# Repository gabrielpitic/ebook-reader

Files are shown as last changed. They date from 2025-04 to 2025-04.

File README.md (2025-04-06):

# OpenBook - Gabriel Pitic

## Diagrama bloc

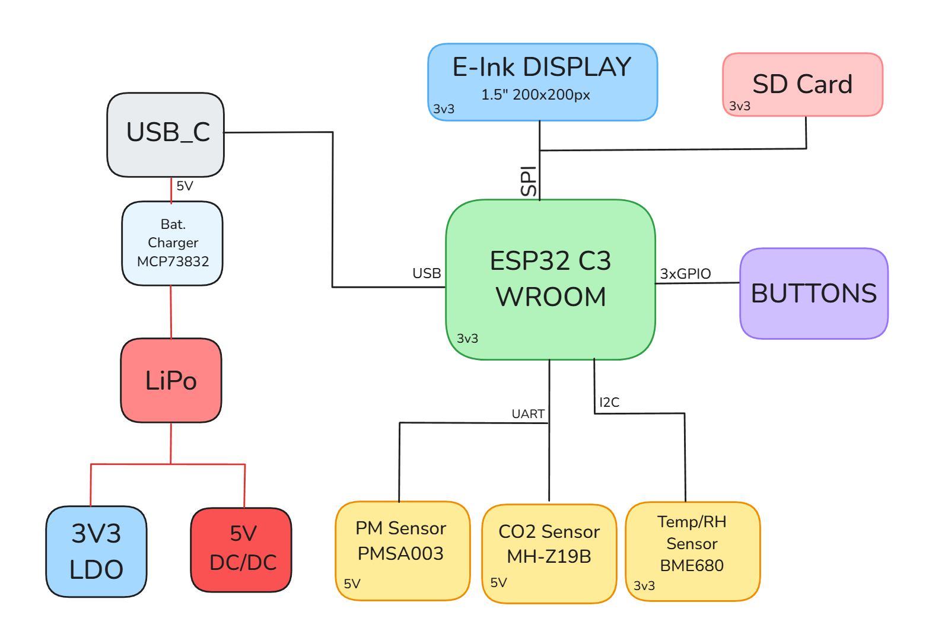
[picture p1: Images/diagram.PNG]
Diagrama bloc


## Bill Of Materials (BOM)
| Componenta | Link | Datasheet |
|---|---|---|
| BD5229G-TR | [Mouser](https://ro.mouser.com/ProductDetail/ROHM-Semiconductor/BD5229G-TR?qs=4kLU8WoGk0vvnhrrYwdszw%3D%3D) | [Datasheet](https://fscdn.rohm.com/en/products/databook/datasheet/ic/power/voltage_detector/bd52xxg-e.pdf)|
| BME688 | [Mouser](https://ro.mouser.com/ProductDetail/Bosch-Sensortec/BME688?qs=IS%252B4QmGtzzqQoVDscqwx3A%3D%3D) | [Datasheet](https://ro.mouser.com/datasheet/2/783/bst_bme688_fl000-2307034.pdf)|
| Bobina | [Mouser](https://ro.mouser.com/ProductDetail/Wurth-Elektronik/744043680?qs=PGXP4M47uW6VkZq%252BkzjrHA%3D%3D) | [Datasheet](https://www.we-online.com/components/products/datasheet/744043680.pdf)|
| Button | [Mouser](https://ro.mouser.com/ProductDetail/CK/KMR221GULCLFS?qs=u2NJ%252B70r0goBXaNk7IrU0Q%3D%3D) |[Datasheet](https://www.ckswitches.com/media/1479/kmr2.pdf)|
| Capacitor 0.1uF / 50V | [Farnell](https://ro.farnell.com/multicomp-pro/mcmlr50v104kx7r/ceramic-capacitor-0-1uf-50v-x7r/dp/1600875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) | [Datasheet](https://www.farnell.com/datasheets/2873577.pdf?_gl=1*x28a2*_gcl_au*MTYwODAzNzc2OC4xNzQzNDM1MjM4)|
| Capacitor 1uF | [Mouser](https://ro.mouser.com/ProductDetail/KEMET/C0402C105K9PACTU?qs=UdQET6xYxVCMExqTDkuPeQ%3D%3D) | [Datasheet](https://ro.mouser.com/datasheet/2/447/KEM_C1006_X5R_SMD-3316465.pdf)|
| Capacitor 1uF / 50V | [Mouser](https://ro.mouser.com/ProductDetail/TDK/C1608X7R1H105K080AB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) | [Datasheet](https://product.tdk.com/system/files/dam/doc/product/capacitor/ceramic/mlcc/catalog/mlcc_commercial_general_en.pdf)|
| Capacitor 4.7uF | [Mouser](https://ro.mouser.com/ProductDetail/KEMET/C0402C475M9PAC7411?qs=cpo3%2FpBou2jRzZxyxJnMGg%3D%3D) | [Datasheet](https://ro.mouser.com/datasheet/2/447/KEM_C1006_X5R_SMD-3316465.pdf)|
| Capacitor 4.7uF / 25V | [Mouser](https://ro.mouser.com/ProductDetail/KYOCERA-AVX/12063C475KAZ2A?qs=%252BdQmOuGyFcG3LdbVp5waMw%3D%3D) | [Datasheet](https://ro.mouser.com/datasheet/2/40/X7RDielectric-2943470.pdf)|
| Capacitor 10uF | [Mouser](https://ro.mouser.com/ProductDetail/KEMET/C0402C106M9PACTU?qs=x4XeXhDQKnp%252Bz0lMlwMC3A%3D%3D) | [Datasheet](https://ro.mouser.com/datasheet/2/447/KEM_C1006_X5R_SMD-3316465.pdf)|
| Capacitor 100nF | [Mouser](https://ro.mouser.com/ProductDetail/KEMET/C0402C104K4RAL?qs=pIZUS6sqCWCaMuP2QVR%2Fog%3D%3D) | [Datasheet](https://ro.mouser.com/datasheet/2/447/KEM_C1018_X7R_SnPb_SMD-3316276.pdf)|
| Capacitor 100uF TANT | [Mouser](https://ro.mouser.com/ProductDetail/KYOCERA-AVX/TAJW107M010RNJ?qs=Wtp%252Bf%2FAeVqIH8v1VxV%252B1Rg%3D%3D) | [Datasheet](https://ro.mouser.com/datasheet/2/40/TAJ-3165264.pdf)|
| Capacitor SUPERCAP | [Mouser](https://ro.mouser.com/ProductDetail/Seiko-Semiconductors/CPH3225A?qs=3etwrb1wR%252BhUOph6lAO7eg%3D%3D) | [Datasheet](https://ro.mouser.com/datasheet/2/360/Seiko_Instruments_MicroBattery_E_20230330_2024Jan_-3561061.pdf)|
| CHG_LED | [CPC](https://cpc.farnell.com/kingbright/kpg-1608zgc/led-smd-0603-grn/dp/SC20796) | [Datasheet](https://www.farnell.com/datasheets/2046349.pdf)|
| DMG2305UX-7 | [Mouser](https://ro.mouser.com/ProductDetail/Diodes-Incorporated/DMG2305UX-7?qs=L1DZKBg7t5F%2FNBHrjfxC%252Bg%3D%3D) | [Datasheet](https://www.diodes.com/assets/Datasheets/DMG2305UX.pdf)|
| DS3231SN# | [Mouser](https://ro.mouser.com/ProductDetail/Analog-Devices-Maxim-Integrated/DS3231SN?qs=1eQvB6Dk1vhUlr8%2FOrV0Fw%3D%3D) | [Datasheet](https://ro.mouser.com/datasheet/2/609/DS3231-3421123.pdf)|
| ESP32-C6-WROOM-1-N8 | [Mouser](https://ro.mouser.com/ProductDetail/Espressif-Systems/ESP32-C6-WROOM-1-N8?qs=8Wlm6%252BaMh8ST02Gmwp74cw%3D%3D) | [Datasheet](https://ro.mouser.com/datasheet/2/891/Espressif_ESP32_C6_WROOM_1__Datasheet_V0_1_PRELIMI-3239987.pdf)|
| FH34SRJ-24S-0.5SH_99_ | [Mouser](https://ro.mouser.com/ProductDetail/Hirose-Connector/FH34SRJ-24S-0.5SH99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) | [Datasheet](https://ro.mouser.com/datasheet/2/185/FH34SRJ_24S_0_5SH_99__CL0580_1255_6_99_2DDrawing_0-1615044.pdf)|
| 112A-TAAR-R03_ATTEND | [LCSC](https://www.lcsc.com/product-detail/SD-Card-Connectors_Attend-Technology-112A-TAAR-R03_C6970445.html) | [Datasheet](https://www.lcsc.com/datasheet/lcsc_datasheet_2411220717_Attend-Technology-112A-TAAR-R03_C6970445.pdf)|
| MAX17048G+T10 | [Mouser](https://ro.mouser.com/ProductDetail/Analog-Devices-Maxim-Integrated/MAX17048G%2bT10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) | [Datasheet](https://ro.mouser.com/datasheet/2/609/MAX17048_MAX17049-3469099.pdf)|
| MBR0530 | [Mouser](https://ro.mouser.com/ProductDetail/onsemi/MBR0530T3G?qs=3JMERSakebpEmdUS6GetdQ%3D%3D) | [Datasheet](https://www.onsemi.com/products/discrete-power-modules/schottky-diodes-schottky-rectifiers/mbr0530t3g)|
| MCP73831 | [Mouser](https://ro.mouser.com/ProductDetail/Microchip-Technology/MCP73831-2ACI-MC?qs=hH%252BOa0VZEiBneYTVdpuVdg%3D%3D) | [Datasheet](https://ro.mouser.com/datasheet/2/268/MCP73831_Family_Data_Sheet_DS20001984H-3441711.pdf)|
| PFMF.050.1 | [Mouser](https://ro.mouser.com/ProductDetail/Schurter/PFMF.050.2?qs=1auRipcfynCums5v1iucSA%3D%3D) | [Datasheet](https://ro.mouser.com/datasheet/2/358/typ_PFMF-1275918.pdf)|
| PGB1010603MR | [Mouser](https://ro.mouser.com/ProductDetail/Littelfuse/PGB1010603MR?qs=gu7KAQ731URLg4GSnNNN7Q%3D%3D) | [Datasheet](https://www.littelfuse.com/assetdocs/pulseguard-esd-suppressors-pgb1-datasheet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)|
| QWIIC_RIGHT_ANGLEA | [Mouser](https://ro.mouser.com/ProductDetail/JST-Commercial/SM04B-SRSS-TBLFSN?qs=cdbOS8ANM9B3FdyA6cNU2A%3D%3D) | [Datasheet](https://ro.mouser.com/datasheet/2/564/eSR_SZ-3476820.pdf)|
| Resistor 0.47 | [Mouser](https://ro.mouser.com/ProductDetail/Vishay-Beyschlag/MCT06030C4700FP500?qs=XsZ9OvPb0dt82KlzjdcMjQ%3D%3D) | [Datasheet](https://www.vishay.com/docs/28705/mcx0x0xpro.pdf)|
| Resistor 2k | [Venkel](https://www.venkel.com/part/CR0402-16W-2002FT) | [Datasheet](https://data.venkel.com/documents/cr-series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.)|
| Resistor 5k1 | [Venkel](https://venkel.com/part/CR0402-10W-5101FT) | [Datasheet](https://data.venkel.com/documents/cr-series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.)|
| Resistor 10K | [DigiKey](https://www.digikey.com/en/products/detail/venkel/CR0402-10W-102JT/12332774) | [Datasheet](https://data.venkel.com/documents/cr-series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.)|
| Resistor 100K | [Venkel](https://venkel.com/part/CR0402-16W-1003FT) | [Datasheet](https://data.venkel.com/documents/cr-series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.)|
| SAMACSYS_PARTS_USB4110-GF-A | [Mouser](https://ro.mouser.com/ProductDetail/GCT/USB4110-GF-A?qs=KUoIvG%2F9IlYiZvIXQjyJeA%3D%3D) | [Datasheet](https://ro.mouser.com/datasheet/2/837/GCT_USB4110_Product_Drawing___20k_cycles-3455479.pdf)|
| SD0805S020S1R0 | [Mouser](https://ro.mouser.com/ProductDetail/KYOCERA-AVX/SD0805S020S1R0?qs=jCA%252BPfw4LHbpkAoSnwrdjw%3D%3D) | [Datasheet](https://ro.mouser.com/datasheet/2/40/schottky-3165252.pdf)|
| SI1308EDL-T1-GE3 | [Mouser](https://ro.mouser.com/ProductDetail/Vishay-Semiconductors/SI1308EDL-T1-GE3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) | [Datasheet](https://www.vishay.com/docs/63399/si1308edl.pdf)|
| USBLC6-2SC6Y | [Mouser](https://ro.mouser.com/ProductDetail/STMicroelectronics/USBLC6-2SC6Y?qs=gNDSiZmRJS%2FOgDexvXkdow%3D%3D) | [Datasheet](https://ro.mouser.com/datasheet/2/389/usblc6_2sc6y-1852505.pdf)|
| W25Q512JVEIQ | [Mouser](https://ro.mouser.com/ProductDetail/Winbond/W25Q512JVEIQ?qs=l7cgNqFNU1jw6svr3at6tA%3D%3D) | [Datasheet](https://ro.mouser.com/datasheet/2/949/Winbond_W25Q512JV_Datasheet-3240039.pdf)|
| XC6220A331MR-G | [Mouser](https://ro.mouser.com/ProductDetail/Torex-Semiconductor/XC6220A331MR-G?qs=AsjdqWjXhJ8ZSWznL1J0gg%3D%3D) | [Datasheet](https://ro.mouser.com/datasheet/2/760/xc6220-3371556.pdf)|

## Descrierea Functionalitatii Hardware (Arhitectura Hardware)

- **OpenBook** integrează un microcontroler **ESP32-C6** cu suport **WiFi** și **Bluetooth**, care coordonează funcționarea generală a dispozitivului.

- **Alimentarea** se face fie prin **USB-C**, fie printr-o **baterie Li-Po** reîncărcabilă, cu circuite dedicate pentru stabilizarea tensiunii și încărcare în siguranță. 

- **Ecranul e-paper** beneficiază de un sistem separat pentru generarea tensiunilor necesare.

- Dispozitivul dispune de opțiuni variate de conectivitate și extensie: **port USB-C** pentru alimentare și date, **slot microSD** pentru stocare suplimentară, **conector FPC** pentru afișaj și **port Qwiic** pentru senzori adiționali.

- Componente auxiliare precum memoria flash de 64MB, ceasul RTC, senzorul ambiental și circuitul de monitorizare a bateriei contribuie la funcționarea autonomă și adaptabilă a sistemului.

## Design Log

- Am modificat pozitionarea butoanelor din enclosure pentru a se potrivi cu piesele 3D de pe PCB.
- Am minimizat trecerea intre layere a  traseelor de putere prin trasarea lor inainte de restul rutelor.
- Am adus componentele ce au  mufe de iesire spre exteriorul PCB-ului.

## Pinout ESP32-C6-WROOM-1-N8

| Pin | Semnal | Descriere |
|---|---|---|
| IO0 | INT_RTC | Semnal de întrerupere de la modulul RTC |
| IO1 | 32KHz | Semnal de 32KHz utilizat ca ceas |
| IO2 | MISO | Comunicație SPI cu cardul SD |
| IO3 | EPD_BUSY | Semnal ocupat de la e-paper |
| IO4 | SS_SD | Selectare card SD |
| IO5 | EPD_DC | Control date/comandă pentru e-paper |
| IO6 | SCK | Semnal SPI Clock |
| IO7 | MOSI | Semnal SPI Date de ieșire |
| IO8 | GPIO8 | Pin general-purpose |
| IO9 | IO/BOOT | Buton pentru inițiere boot |
| IO10 | EPD_CS | Selectare chip pentru e-paper |
| IO11 | FLASH_CS | Selectare chip pentru memoria flash |
| IO12 | USB_D- | Comunicație USB (minus) |
| IO13 | USB_D+ | Comunicație USB (plus) |
| IO15 | IO/CHANGE | Buton pentru schimbare de pagină |
| IO16 | TX | Transmitere serială (UART) |
| IO17 | RX | Recepție serială (UART) |
| IO18 | RTC_RST | Reset pentru modulul RTC |
| IO19 | I2C_PW | Control alimentare pentru periferice I2C |
| IO20 | EPD_3V3_C | Control alimentare e-paper |
| IO21 | SDA | Linie de date I2C |
| IO22 | SCL | Linie de ceas I2C |
| IO23 | EPD_RST | Reset pentru e-paper |
| EN | RESET | Reset general pentru ESP32 |

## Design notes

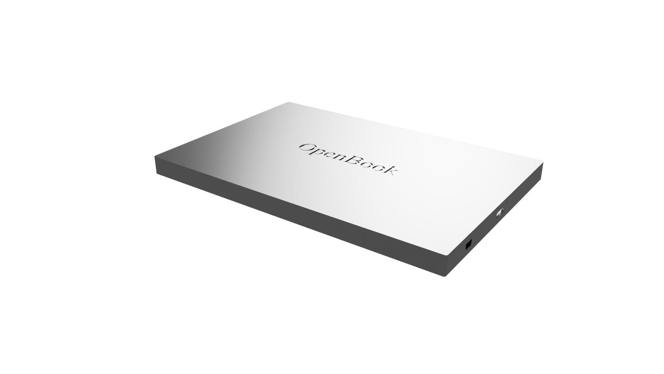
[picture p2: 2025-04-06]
Images/FULL OpenBook.png

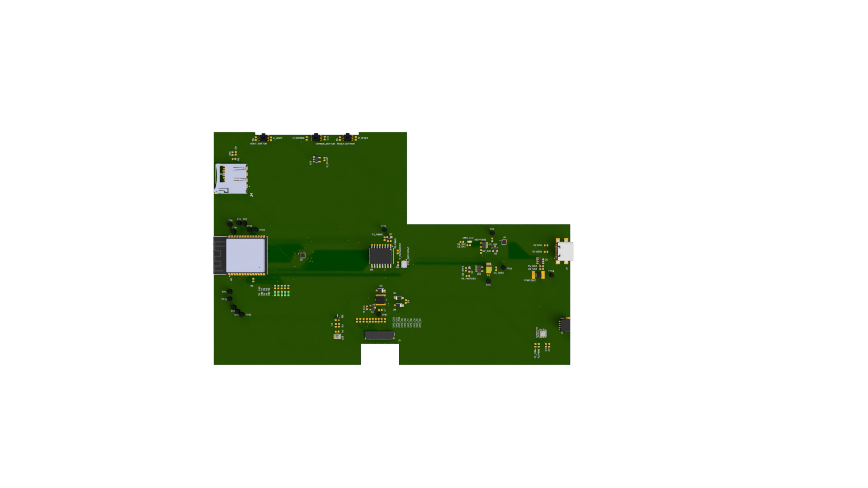
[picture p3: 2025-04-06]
Images/PCB TOP VIEW.png

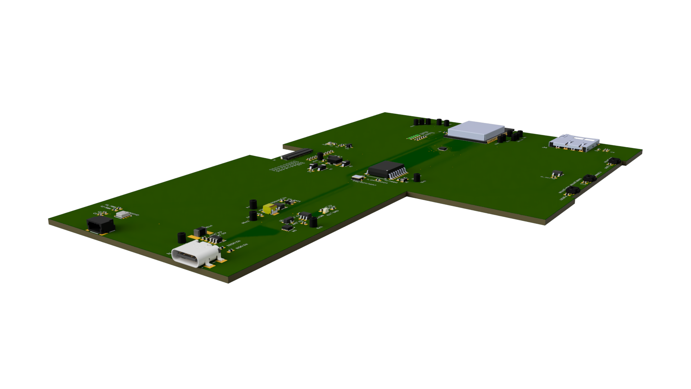
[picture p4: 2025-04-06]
Images/PCB SIDE VIEW 2.png

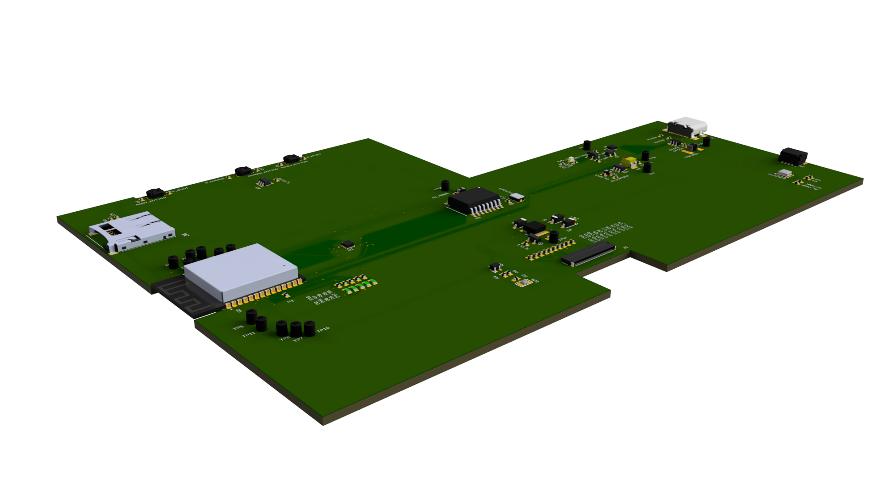
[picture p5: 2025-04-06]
Images/PCB SIDE VIEW.png

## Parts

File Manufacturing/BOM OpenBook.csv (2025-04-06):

Qty | Value | Device | Package | Parts | Description | ARROW_PART_NUMBER | ARROW_PRICE-STOCK | AVAILABILITY | CENTROID_NOT_SPECIFIED | CHECK_PRICES | COPYRIGHT | DATASHEET | DESCRIPTION | DIGIKEY_DESCRIPTION | DIGIKEY_PART_NUMBER | HEIGHT | LEAD_FREE | MANUFACTURER_NAME | MANUFACTURER_PART_NUMBER | MF | MFR_NAME | MOUSER_PART_NUMBER | MOUSER_PRICE-STOCK | MP | MPN | PACKAGE | POPULARITY | PREFIX | PRICE | PROD_ID | PURCHASE-URL | ROHS | SNAPEDA_LINK | SPICEMODEL | SPICEPREFIX | TEMPERATURE_RANGE_HIGH | TEMPERATURE_RANGE_LOW | TP_SIGNAL_NAME | VALUE
1 |  | ADAFRUIT_LEDCHIP-LED0603 | ADAFRUIT_CHIP-LED0603 | CHG_LED | LED
1 |  | EAGLE-LTSPICE_CC0402 | ESP32_WROVER_EAGLE-LTSPICE_C0402 | D10 | CAPACITOR, European symbol |  |  |  |  |  |  |  |  |  |  |  |  |  |  |  |  |  |  |  |  |  |  |  |  |  |  |  |  | NONE | C
1 |  | SJ | SJ | SJ1 | SMD solder JUMPER |  |  |  |  |  |  |  |  |  |  |  |  |  |  |  |  |  |  |  |  |  | 3
1 | 0.1uF/50V | EAGLE-LTSPICE_CC0402 | ESP32_WROVER_EAGLE-LTSPICE_C0402 | EPD_C5 | CAPACITOR, European symbol |  |  |  |  |  |  |  |  |  |  |  |  |  |  |  |  |  |  |  |  |  |  |  |  |  |  |  |  | NONE | C
1 | 0.47 | ESP32_WROVER_EAGLE-LTSPICE_RR0402 | ESP32_WROVER_EAGLE-LTSPICE_R0402 | R3 | RESISTOR, European symbol |  |  |  |  |  |  |  |  |  |  |  |  |  |  |  |  |  |  |  |  |  |  |  |  |  |  |  |  | NONE | R
1 | 100K | ESP32_WROVER_EAGLE-LTSPICE_RR0402 | ESP32_WROVER_EAGLE-LTSPICE_R0402 | R1_PWRUSB | RESISTOR, European symbol |  |  |  |  |  |  |  |  |  |  |  |  |  |  |  |  |  |  |  |  |  |  |  |  |  |  |  |  | NONE | R
8 | 100nF | EAGLE-LTSPICE_CC0402 | ESP32_WROVER_EAGLE-LTSPICE_C0402 | C1, C2, C4_USB, C6, C8, C9, C10, C_DELAY | CAPACITOR, European symbol |  |  |  |  |  |  |  |  |  |  |  |  |  |  |  |  |  |  |  |  |  |  |  |  |  |  |  |  | NONE | C
1 | 100uF TANT | RCL_CPOL-EUCT3528 | RCL_CT3528 | C3 | POLARIZED CAPACITOR, European symbol |  |  |  |  |  |  |  |  |  |  |  |  |  |  |  |  |  |  |  |  |  | 0 |  |  |  |  |  |  |  | C
1 | 10K | EAGLE-LTSPICE_CC0402 | ESP32_WROVER_EAGLE-LTSPICE_C0402 | R_BOOT | CAPACITOR, European symbol |  |  |  |  |  |  |  |  |  |  |  |  |  |  |  |  |  |  |  |  |  |  |  |  |  |  |  |  | NONE | C
15 | 10K | ESP32_WROVER_EAGLE-LTSPICE_RR0402 | ESP32_WROVER_EAGLE-LTSPICE_R0402 | R1, R1_PINH, R1_PINH1, R2-PINH, R2-PINH1, R4, R5, R6, R7, R8, R9, R10, R_CHANGE, R_CL1, R_RESET | RESISTOR, European symbol |  |  |  |  |  |  |  |  |  |  |  |  |  |  |  |  |  |  |  |  |  |  |  |  |  |  |  |  | NONE | R
1 | 10uF | EAGLE-LTSPICE_CC0402 | ESP32_WROVER_EAGLE-LTSPICE_C0402 | C7 | CAPACITOR, European symbol |  |  |  |  |  |  |  |  |  |  |  |  |  |  |  |  |  |  |  |  |  |  |  |  |  |  |  |  | NONE | C
1 | 112A-TAAR-R03_ATTEND112ATA | 112A-TAAR-R03_ATTEND112ATA | 112ATAARR03ATTEND | J4 | Micro SD Card Socket, Push-Push Type, Top Mount, SMT, H=1.83mm, 10u
1 | 15 | ESP32_WROVER_EAGLE-LTSPICE_RR0402 | ESP32_WROVER_EAGLE-LTSPICE_R0402 | R_CAPACITOR | RESISTOR, European symbol |  |  |  |  |  |  |  |  |  |  |  |  |  |  |  |  |  |  |  |  |  |  |  |  |  |  |  |  | NONE | R
1 | 1uF | EAGLE-LTSPICE_CC0402 | ESP32_WROVER_EAGLE-LTSPICE_C0402 | C5 | CAPACITOR, European symbol |  |  |  |  |  |  |  |  |  |  |  |  |  |  |  |  |  |  |  |  |  |  |  |  |  |  |  |  | NONE | C
9 | 1uF/50V | EAGLE-LTSPICE_CC0402 | ESP32_WROVER_EAGLE-LTSPICE_C0402 | EPD_C1, EPD_C2, EPD_C6, EPD_C7, EPD_C8, EPD_C9, EPD_C10, EPD_C11, EPD_C12 | CAPACITOR, European symbol |  |  |  |  |  |  |  |  |  |  |  |  |  |  |  |  |  |  |  |  |  |  |  |  |  |  |  |  | NONE | C
1 | 2.2 | ESP32_WROVER_EAGLE-LTSPICE_RR0402 | ESP32_WROVER_EAGLE-LTSPICE_R0402 | R2 | RESISTOR, European symbol |  |  |  |  |  |  |  |  |  |  |  |  |  |  |  |  |  |  |  |  |  |  |  |  |  |  |  |  | NONE | R
1 | 200 | ESP32_WROVER_EAGLE-LTSPICE_RR0402 | ESP32_WROVER_EAGLE-LTSPICE_R0402 | R1_BAT | RESISTOR, European symbol |  |  |  |  |  |  |  |  |  |  |  |  |  |  |  |  |  |  |  |  |  |  |  |  |  |  |  |  | NONE | R
2 | 20V/4.2A/52mO/1.4W | ESP32_WROVER_SPARKFUN-DISCRETESEMI_MOSFET_PCH-DMG2305UX-7 | ESP32_WROVER_SPARKFUN-DISCRETESEMI_SOT23-3 | Q1, Q2 | P-channel MOSFETs |  |  |  |  |  |  |  |  |  |  |  |  |  |  |  |  |  |  |  |  |  |  |  |  | TRAN-14388 |  |  |  |  |  |  |  |  | 20V/4.2A/52mO/1.4W
1 | 2K | ESP32_WROVER_EAGLE-LTSPICE_RR0402 | ESP32_WROVER_EAGLE-LTSPICE_R0402 | R2_BAT | RESISTOR, European symbol |  |  |  |  |  |  |  |  |  |  |  |  |  |  |  |  |  |  |  |  |  |  |  |  |  |  |  |  | NONE | R
5 | 4.7uF | EAGLE-LTSPICE_CC0402 | ESP32_WROVER_EAGLE-LTSPICE_C0402 | C1_BAT, C1_BAT1, C1_BAT2, C2_BAT, C5_USB | CAPACITOR, European symbol |  |  |  |  |  |  |  |  |  |  |  |  |  |  |  |  |  |  |  |  |  |  |  |  |  |  |  |  | NONE | C
1 | 4.7uF/25V | EAGLE-LTSPICE_CC0402 | ESP32_WROVER_EAGLE-LTSPICE_C0402 | C4 | CAPACITOR, European symbol |  |  |  |  |  |  |  |  |  |  |  |  |  |  |  |  |  |  |  |  |  |  |  |  |  |  |  |  | NONE | C
2 | 5k1 | ESP32_WROVER_EAGLE-LTSPICE_RR0402 | ESP32_WROVER_EAGLE-LTSPICE_R0402 | R2-USB, R2-USB1 | RESISTOR, European symbol |  |  |  |  |  |  |  |  |  |  |  |  |  |  |  |  |  |  |  |  |  |  |  |  |  |  |  |  | NONE | R
1 | 68uH | 744043680IND_4828-WE-TPC_WRE | IND_4828-WE-TPC_WRE | L1 |  |  |  |  |  |  | Copyright (C) 2024 Ultra Librarian. All rights reserved. |  |  |  |  |  |  |  | 744043680 |  | Wurth Electronics
1 | BD5229G-TR | BD5229G-TR | SOT95P280X125-5N | IC1 | Voltage Detector with Adjustable Delay Time: CMOS processes are utilized to develop high precision, low current consumption CMOS reset ICs that allow arbitrary setting of the delay time. The extensive lineup includes both Nch Open Drain and CMOS output types in a wide range of detection voltages (from 2.3V to 6.0V, in 0.1V steps), enabling selection of the ideal solution based on customer requirements. In addition, the entire series is of course both lead-free and RoHS-compliant. |  |  |  |  |  |  |  | Voltage Detector with Adjustable Delay Time: CMOS processes are utilized to develop high precision | low current consumption CMOS reset ICs that allow arbitrary setting of the delay time. The extensive lineup includes both Nch Open Drain and CMOS output types in a wide range of detection voltages (from 2.3V to 6.0V | in 0.1V steps) | enabling selection of the ideal solution based on customer requirements. In addition | the entire series is of course both lead-free and RoHS-compliant. |  |  | 1.25mm |  | ROHM Semiconductor | BD5229G-TR |  |  | 755-BD5229G-TR | https://www.mouser.co.uk/ProductDetail/ROHM-Semiconductor/BD5229G-TR?qs=4kLU8WoGk0vvnhrrYwdszw%3D%3D
3 | BUTTON_CUSYOMV1 | BUTTON_CUSYOMV1 | MYBUTTON | BOOT_BUTTON, CHANGE_BUTTON, RESET_BUTTON
1 | CPH3225A | CPH3225A | CAPCP3225X100N | C10_SUPERCAP | Cap 0.011F 3.3V 1210 Flat Check availability |  |  | Not in stock |  | https://www.snapeda.com/parts/CPH3225A/Seiko+Instruments/view-part/?ref=eda |  |  | 11 mF (EDLC) Supercapacitor 3.3 V 1210 (3225 Metric) - - |  |  |  |  |  |  | Seiko Instruments |  |  |  | CPH3225A |  | 1210 Seiko |  |  | None |  | https://www.snapeda.com/api/url_track_click_mouser/?unipart_id=562593&manufacturer=Seiko Instruments&part_name=CPH3225A&search_term=None |  | https://www.snapeda.com/parts/CPH3225A/Seiko+Instruments/view-part/?ref=snap
1 | DS3231SN# | DS3231SN# | SOIC127P1032X265-16N | U3 | Real Time Clock Serial 16-Pin SOIC W T/R Check availability |  |  | In Stock |  | https://www.snapeda.com/parts/DS3231SN%23/Analog+Devices/view-part/?ref=eda |  |  | Extremely Accurate I²C-Integrated RTC/TCXO/Crystal |  |  |  |  |  |  | Analog Devices |  |  |  | DS3231SN# |  | SOIC-16 Maxim |  |  | None |  | https://www.snapeda.com/api/url_track_click_mouser/?unipart_id=99048&manufacturer=Analog Devices&part_name=DS3231SN#&search_term=None |  | https://www.snapeda.com/parts/DS3231SN%23/Analog+Devices/view-part/?ref=snap
1 | ESP32-C6-WROOM-1-N8 | ESP32-C6-WROOM-1-N8 | ESP32-C6-WROOM-1-N8 | U2 | Check availability
1 | ESP32C6_VARISTOR | ESP32C6_VARISTOR | ESP32C6_VARISTOR_CT/CN1812 | PFMF.050.1 | VARISTOR
2 | ESP32_WROVER_AVX---SD0805S020S1R0_AVX_SD0805S020S1R0_0_0AVX_SD0805S020S1R0_0_0 | ESP32_WROVER_AVX---SD0805S020S1R0_AVX_SD0805S020S1R0_0_0AVX_SD0805S020S1R0_0_0 | ESP32_WROVER_AVX---SD0805S020S1R0_AVX_SD0805S020S1R0_0 | D2, D7 | Schottky Barrier Rectifier Diode |  |  |  | No |  |  | http://datasheets.avx.com/schottky.pdf |  | DIODE SCHOTTKY 20V 1A 0805 | 478-7800-1-ND |  | yes |  |  | AVX |  | 581-SD0805S020S1R0 |  |  |  | 0805 (2012 metric) |  | D |  |  |  | yes |  |  |  | +125°C | -55°C
1 | ESP32_WROVER_BME680_BME680 | ESP32_WROVER_BME680_BME680 | ESP32_WROVER_BME680_PSON80P300X300X100-8N | SENSOR2 | Integrated Environmental Unit |  |  | Unavailable |  |  |  |  | Integrated Environmental Unit |  |  |  |  |  |  | Bosch Sensortec |  |  |  | BME680 |  | LGA-8 Bosch Tools |  |  | None
1 | ESP32_WROVER_SPARKFUN-IC-POWER_MCP73831 | ESP32_WROVER_SPARKFUN-IC-POWER_MCP73831 | ESP32_WROVER_SPARKFUN-IC-POWER_SOT23-5 | MCP73831 | MCP73831T Li-Ion, Li-Pol Controller |  |  |  |  |  |  |  |  |  |  |  |  |  |  |  |  |  |  |  |  |  |  |  |  | IC-09995
1 | FH34SRJ-24S-0.5SH_99_ | FH34SRJ-24S-0.5SH_99_ | FH34SRJ24S05SH99 | J1 | (0.50mm) Surface Mount, Right Angle |  |  |  |  |  |  |  | 24 Position FFC | FPC Connector Contacts | (0.50mm) Surface Mount | Right Angle |  |  | 1.1mm |  | Hirose | FH34SRJ-24S-0.5SH(99) |  |  | 798-FH34SRJ24S05SH99 | https://www.mouser.co.uk/ProductDetail/Hirose-Connector/FH34SRJ-24S-0.5SH99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
1 | MAX17048G+T10 | MAX17048G+T10 | SON50P200X200X80-9N | U4 | Check availability |  |  | In Stock |  | https://www.snapeda.com/parts/MAX17048G+T10/Analog+Devices/view-part/?ref=eda |  |  | 3µA 1-Cell/2-Cell Fuel Gauge with ModelGauge |  |  |  |  |  |  | Analog Devices |  |  |  | MAX17048G+T10 |  | TDFN-8 Maxim |  |  | None |  | https://www.snapeda.com/api/url_track_click_mouser/?unipart_id=329239&manufacturer=Analog Devices&part_name=MAX17048G+T10&search_term=None |  | https://www.snapeda.com/parts/MAX17048G+T10/Analog+Devices/view-part/?ref=snap
3 | MBR0530 | MBR0530 | SOD3716X135N | D3, D4, D5 | ON SEMICONDUCTOR - MBR0530 - DIODE, SCHOTTKY, 0.5A, 30V, SOD-123 |  |  | In Stock |  | https://www.snapeda.com/parts/MBR0530/Onsemi/view-part/?ref=eda |  |  | Diode Schottky 30 V 500mA Surface Mount SOD-123 |  |  |  |  |  |  | ON Semiconductor |  |  |  | MBR0530 |  | SOD-123-2 ON Semiconductor |  |  | None |  | https://www.snapeda.com/api/url_track_click_mouser/?unipart_id=179458&manufacturer=ON Semiconductor&part_name=MBR0530&search_term=None |  | https://www.snapeda.com/parts/MBR0530/Onsemi/view-part/?ref=snap
5 | PGB1010603MR | PGB1010603MR | DIOC1608X36N | D6, D8, D9, D11, D12 | Check availability |  |  | In Stock |  | https://www.snapeda.com/parts/PGB1010603MR/Littelfuse/view-part/?ref=eda |  |  | 150V (Typ) Clamp - Ipp Tvs Diode Surface Mount 0603 (1608 Metric) |  |  |  |  |  |  | Littelfuse Inc. |  |  |  | PGB1010603MR |  | 0603 Littelfuse Inc. |  |  | None |  | https://www.snapeda.com/api/url_track_click_mouser/?unipart_id=5659453&manufacturer=Littelfuse Inc.&part_name=PGB1010603MR&search_term=None |  | https://www.snapeda.com/parts/PGB1010603MR/Littelfuse/view-part/?ref=snap
1 | QWIIC_RIGHT_ANGLE | QWIIC_CONNECTORJS-1MM | JST04_1MM_RA | J3 | SparkFun I2C Standard Qwiic Connector |  |  |  |  |  |  |  |  |  |  |  |  |  |  |  |  |  |  |  |  |  |  |  |  | CONN-13694 |  |  |  |  |  |  |  |  | QWIIC_RIGHT_ANGLE
1 | SAMACSYS_PARTS_USB4110-GF-A | SAMACSYS_PARTS_USB4110-GF-A | SAMACSYS_PARTS_USB4110GFA | J2 | CONN USB 2.0 TYPE-C R/A SMT
1 | SI1308EDL-T1-GE3 | SI1308EDL-T1-GE3 | SOT65P210X110-3N | Q3 | MOSFET N-Ch 30V 1.5A TrenchFET SC70 Vishay Si1308EDL-T1-GE3 N-channel MOSFET Transistor, 1.5 A, 30 V, 3-Pin SC-70 |  |  | In Stock |  | https://www.snapeda.com/parts/SI1308EDL-T1-GE3/Vishay+Siliconix/view-part/?ref=eda |  |  | Si1308EDL-T1-GE3 N-channel MOSFET Transistor | 1.5 A | 30 V | 3-Pin SC-70 | Siliconix / Vishay SI1308EDL-T1-GE3 |  |  |  |  |  |  | Vishay Siliconix |  |  |  | SI1308EDL-T1-GE3 |  | SOT-323 Vishay Semiconductor |  |  | None |  | https://www.snapeda.com/api/url_track_click_mouser/?unipart_id=274603&manufacturer=Vishay Siliconix&part_name=SI1308EDL-T1-GE3&search_term=None |  | https://www.snapeda.com/parts/SI1308EDL-T1-GE3/Vishay+Siliconix/view-part/?ref=snap
17 | TPTP20R | TPTP20R | TP20R | TP1, TP2, TP3, TP4, TP5, TP6, TP7, TP8, TP9, TP10, TP11, TP12, TP13, TP14, TP15, TP16, TP17 | Test pad |  |  |  |  |  |  |  |  |  |  |  |  |  |  |  |  |  |  |  |  |  | 2
1 | USBLC6-2SC6Y | USBLC6-2SC6Y | SOT95P280X145-6N | D1 | Low Cap. ESD Protection Auto SOT-23-6 STMicroelectronics USBLC6-2SC6Y, Dual Uni-Directional TVS Diode Array, 6-Pin SOT-23 |  |  | In Stock |  | https://www.snapeda.com/parts/USBLC6-2SC6Y/STMicroelectronics/view-part/?ref=eda |  |  | 17V Clamp 5A (8/20µs) Ipp Tvs Diode Surface Mount SOT-23-6 |  |  |  |  |  |  | STMicroelectronics |  |  |  | USBLC6-2SC6Y |  | SOT-23-6 STMicroelectronics |  |  | None |  |  |  | https://www.snapeda.com/parts/USBLC6-2SC6Y/STMicroelectronics/view-part/?ref=snap
1 | W25Q512JVEIQ | W25Q512JVEIQ | SON50P200X200X80-9N | U1 | Check availability |  |  | In Stock |  | https://www.snapeda.com/parts/W25Q512JVEIQ/Winbond+Electronics/view-part/?ref=eda |  |  | FLASH - NOR Memory IC 512Mb (64M x 8) SPI - Quad I/O 133 MHz 8-WSON (8x6) |  |  |  |  |  |  | Winbond Electronics |  |  |  | W25Q512JVEIQ |  | Package |  |  | None |  |  |  | https://www.snapeda.com/parts/W25Q512JVEIQ/Winbond+Electronics/view-part/?ref=snap
1 | XC6220A331MR-G | XC6220A331MR-G | SOT95P280X120-5N | IC4 | LDO Voltage Regulators |  |  |  |  |  |  |  | LDO Voltage Regulators |  |  | 1.2mm |  | Torex | XC6220A331MR-G |  |  | 865-XC6220A331MR-G | https://www.mouser.co.uk/ProductDetail/Torex-Semiconductor/XC6220A331MR-G?qs=AsjdqWjXhJ8ZSWznL1J0gg%3D%3D

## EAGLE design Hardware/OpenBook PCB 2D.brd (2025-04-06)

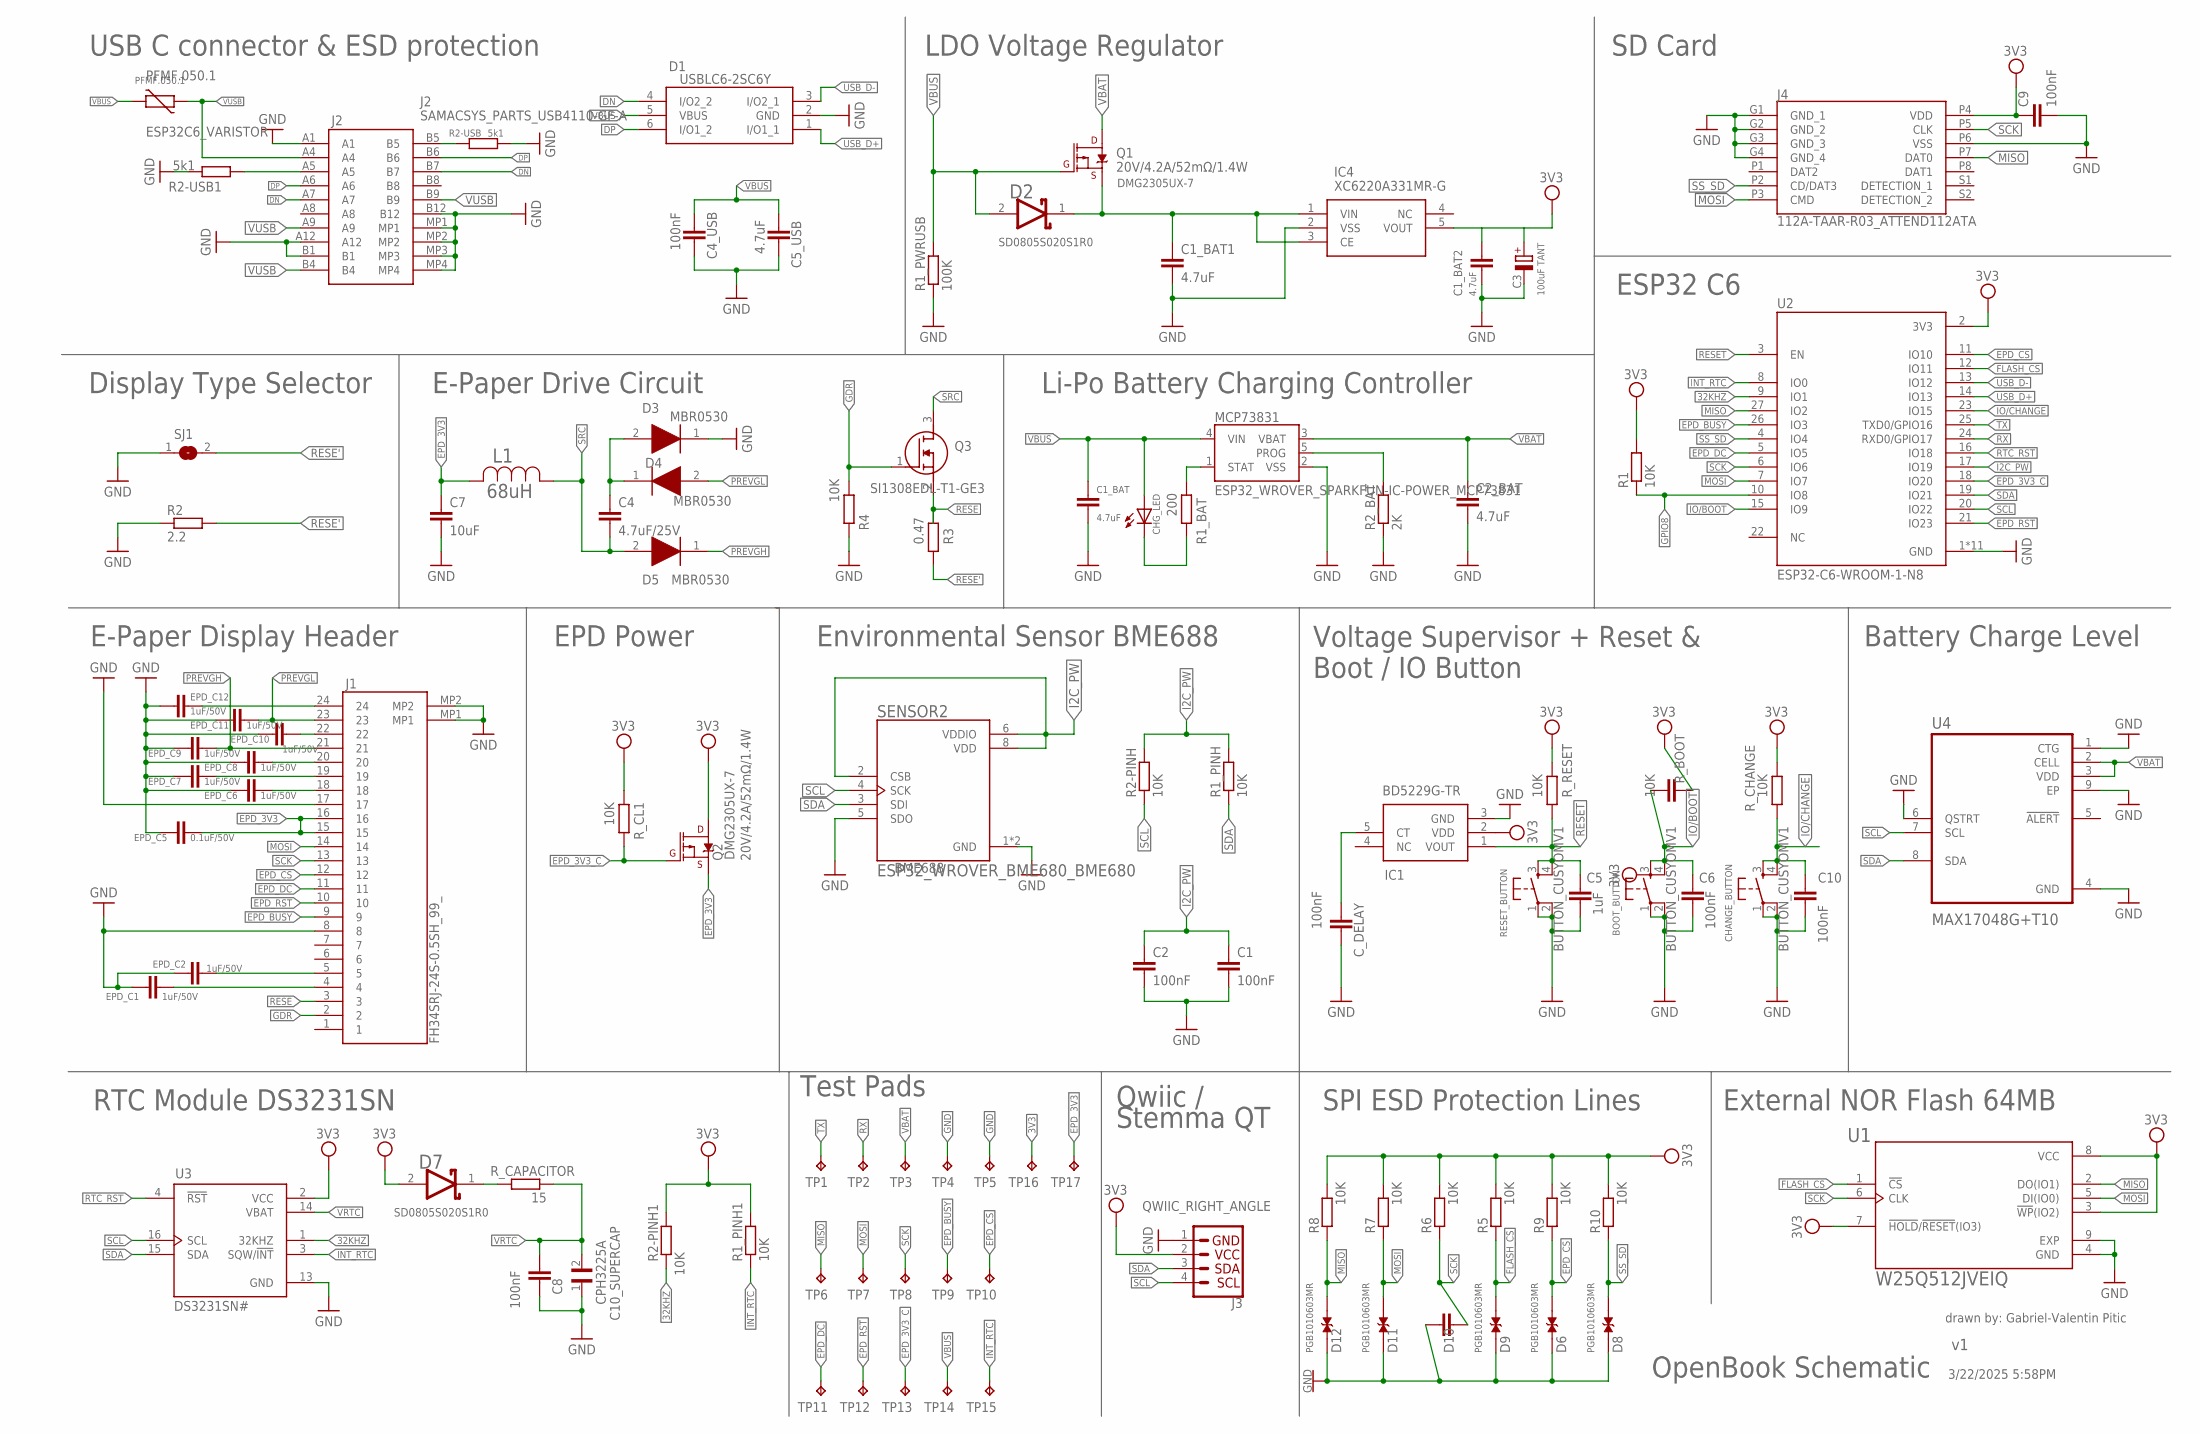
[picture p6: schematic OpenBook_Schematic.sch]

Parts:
BOOT_BUTTON: BUTTON_CUSYOMV1; MYBUTTON
C1, C2, C4_USB, C6, C8, C9, C10: 100nF; ESP32_WROVER_EAGLE-LTSPICE_C0402
C1_BAT, C1_BAT1, C1_BAT2, C2_BAT, C5_USB: 4.7uF; ESP32_WROVER_EAGLE-LTSPICE_C0402
C3: 100uF TANT; RCL_CT3528
C4: 4.7uF/25V; ESP32_WROVER_EAGLE-LTSPICE_C0402
C5: 1uF; ESP32_WROVER_EAGLE-LTSPICE_C0402
C7: 10uF; ESP32_WROVER_EAGLE-LTSPICE_C0402
C10_SUPERCAP: CPH3225A; CAPCP3225X100N
CHANGE_BUTTON: BUTTON_CUSYOMV1; MYBUTTON
CHG_LED: ADAFRUIT_LEDCHIP-LED0603; ADAFRUIT_CHIP-LED0603
C_DELAY: 100nF; ESP32_WROVER_EAGLE-LTSPICE_C0402
D1: USBLC6-2SC6Y; SOT95P280X145-6N
D2, D7: ESP32_WROVER_AVX---SD0805S020S1R0_AVX_SD0805S020S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; ESP32_WROVER_AVX---SD0805S020S1R0_AVX_SD0805S020S1R0_0
D3, D4, D5: MBR0530; SOD3716X135N
D6, D8, D9, D11, D12: PGB1010603MR; DIOC1608X36N
D10: EAGLE-LTSPICE_CC0402; ESP32_WROVER_EAGLE-LTSPICE_C0402
EPD_C1, EPD_C2, EPD_C6, EPD_C7, EPD_C8, EPD_C9, EPD_C10, EPD_C11, EPD_C12: 1uF/50V; ESP32_WROVER_EAGLE-LTSPICE_C0402
EPD_C5: 0.1uF/50V; ESP32_WROVER_EAGLE-LTSPICE_C0402
IC1: BD5229G-TR; SOT95P280X125-5N
IC4: XC6220A331MR-G; SOT95P280X120-5N
J1: FH34SRJ-24S-0.5SH_99_; FH34SRJ24S05SH99
J2: SAMACSYS_PARTS_USB4110-GF-A; SAMACSYS_PARTS_USB4110GFA
J3: QWIIC_RIGHT_ANGLE; JST04_1MM_RA
J4: 112A-TAAR-R03_ATTEND112ATA; 112ATAARR03ATTEND
L1: 68uH; IND_4828-WE-TPC_WRE
MCP73831: ESP32_WROVER_SPARKFUN-IC-POWER_MCP73831; ESP32_WROVER_SPARKFUN-IC-POWER_SOT23-5
PFMF.050.1: ESP32C6_VARISTOR; ESP32C6_VARISTOR_CT/CN1812
Q1, Q2: 20V/4.2A/52mΩ/1.4W; ESP32_WROVER_SPARKFUN-DISCRETESEMI_SOT23-3
Q3: SI1308EDL-T1-GE3; SOT65P210X110-3N
R1, R1_PINH, R1_PINH1, R2-PINH, R2-PINH1, R4, R5, R6, R7, R8, R9, R10: 10K; ESP32_WROVER_EAGLE-LTSPICE_R0402
R1_BAT: 200; ESP32_WROVER_EAGLE-LTSPICE_R0402
R1_PWRUSB: 100K; ESP32_WROVER_EAGLE-LTSPICE_R0402
R2: 2.2; ESP32_WROVER_EAGLE-LTSPICE_R0402
R2-USB, R2-USB1: 5k1; ESP32_WROVER_EAGLE-LTSPICE_R0402
R2_BAT: 2K; ESP32_WROVER_EAGLE-LTSPICE_R0402
R3: 0.47; ESP32_WROVER_EAGLE-LTSPICE_R0402
RESET_BUTTON: BUTTON_CUSYOMV1; MYBUTTON
R_BOOT: 10K; ESP32_WROVER_EAGLE-LTSPICE_C0402
R_CAPACITOR: 15; ESP32_WROVER_EAGLE-LTSPICE_R0402
R_CHANGE: 10K; ESP32_WROVER_EAGLE-LTSPICE_R0402
R_CL1: 10K; ESP32_WROVER_EAGLE-LTSPICE_R0402
R_RESET: 10K; ESP32_WROVER_EAGLE-LTSPICE_R0402
SENSOR2: ESP32_WROVER_BME680_BME680; ESP32_WROVER_BME680_PSON80P300X300X100-8N
SJ1: SJ
TP1, TP2, TP3, TP4, TP5, TP6, TP7, TP8, TP9, TP10, TP11, TP12, TP13, TP14, TP15, TP16, TP17: TPTP20R; TP20R
U1: W25Q512JVEIQ; SON50P200X200X80-9N
U2: ESP32-C6-WROOM-1-N8
U3: DS3231SN#; SOIC127P1032X265-16N
U4: MAX17048G+T10; SON50P200X200X80-9N

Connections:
3V3: C1_BAT2.1, C3.+, C9.1, D7.2 (ANODE), IC1.2 (VDD), IC4.5 (VOUT), J3.2, J4.P4 (VDD), Q2.3 (D), R1.2, R1_PINH1.2, R2-PINH1.2, R5.2, R6.2, R7.2, R8.2, R9.2, R10.2, R_BOOT.2, R_CHANGE.2, R_CL1.2, R_RESET.2, TP16.TP, U1.3 (!WP!(IO2)), U1.7 (!HOLD!/!RESET!(IO3)), U1.8 (VCC), U2.2 (3V3), U3.2 (VCC)
32KHZ: R2-PINH1.1, U2.9 (IO1), U3.1 (32KHZ)
A5_J2: J2.A5, R2-USB1.2
B5_J2: J2.B5, R2-USB.1
CE_VIN: C1_BAT1.1, D2.1 (CATHODE), IC4.1 (VIN), IC4.3 (CE), Q1.2 (S)
CHG_STATUS: CHG_LED.C, MCP73831.1 (STAT), R1_BAT.1, R1_BAT.2
C_DELAY: C_DELAY.1, IC1.5 (CT)
D7_R_CAP: D7.1 (CATHODE), R_CAPACITOR.2
DN: D1.4 (I/O2_2), J2.A7, J2.B7
DP: D1.6 (I/O1_2), J2.A6, J2.B6
EPD_3V3: C7.1, EPD_C5.1, J1.15, J1.16, L1.2, Q2.2 (S), TP17.TP
EPD_3V3_C: Q2.1 (G), R_CL1.1, TP13.TP, U2.18 (IO20)
EPD_BUSY: J1.9, TP9.TP, U2.26 (IO3)
EPD_CS: D6.2, J1.12, R9.1, TP10.TP, U2.11 (IO10)
EPD_DC: J1.11, TP11.TP, U2.5 (IO5)
EPD_RST: J1.10, TP12.TP, U2.21 (IO23)
FLASH_CS: D9.2, R5.1, U1.1 (!CS), U2.12 (IO11)
GDR: J1.2, Q3.1 (G), R4.2
GND: BOOT_BUTTON.1, BOOT_BUTTON.2, C1.2, C1_BAT.2, C1_BAT1.2, C1_BAT2.2, C2.2, C2_BAT.2, C3.-, C4_USB.2, C5.2, C5_USB.2, C6.2, C7.2, C8.2, C9.2, C10.2, C10_SUPERCAP.1, CHANGE_BUTTON.1, CHANGE_BUTTON.2, C_DELAY.2, D1.2 (GND), D3.1 (K), D6.1, D8.1, D9.1, D10.1, D11.1, D12.1, EPD_C1.2, EPD_C2.1, EPD_C5.2, EPD_C6.2, EPD_C7.2, EPD_C8.2, EPD_C9.2, EPD_C10.2, EPD_C11.2, EPD_C12.2, IC1.3 (GND), IC4.2 (VSS), J1.8, J1.17, J1.MP1, J1.MP2, J2.A1, J2.A12, J2.B1, J2.B12, J2.MP1, J2.MP2, J2.MP3, J2.MP4, J3.1, J4.G1 (GND_1), J4.G2 (GND_2), J4.G3 (GND_3), J4.G4 (GND_4), J4.P6 (VSS), MCP73831.2 (VSS), R1_PWRUSB.1, R2.1, R2-USB.2, R2-USB1.1, R2_BAT.1, R4.1, RESET_BUTTON.1, RESET_BUTTON.2, SENSOR2.1 (GND), SENSOR2.5 (SDO), SENSOR2.7 (GND), SJ1.1, TP4.TP, TP5.TP, U1.4 (GND), U1.9 (EXP), U2.1 (GND), U2.28 (GND), U2.29_1 (GND), U2.29_2 (GND), U2.29_3 (GND), U2.29_4 (GND), U2.29_5 (GND), U2.29_6 (GND), U2.29_7 (GND), U2.29_8 (GND), U2.29_9 (GND), U3.13 (GND), U4.1 (CTG), U4.4 (GND), U4.6 (QSTRT), U4.9 (EP)
GPIO8: R1.1, U2.10 (IO8)
I2C_PW: C1.1, C2.1, R1_PINH.2, R2-PINH.2, SENSOR2.2 (CSB), SENSOR2.6 (VDDIO), SENSOR2.8 (VDD), U2.17 (IO19)
INT_RTC: R1_PINH1.1, TP15.TP, U2.8 (IO0), U3.3 (SQW/!INT)
IO/BOOT: BOOT_BUTTON.3, BOOT_BUTTON.4, C6.1, R_BOOT.1, U2.15 (IO9)
IO/CHANGE: C10.1, CHANGE_BUTTON.3, CHANGE_BUTTON.4, R_CHANGE.1, U2.23 (IO15)
MISO: D12.2, J4.P7 (DAT0), R8.1, TP6.TP, U1.2 (DO(IO1)), U2.27 (IO2)
MOSI: D11.2, J1.14, J4.P3 (CMD), R7.1, TP7.TP, U1.5 (DI(IO0)), U2.7 (IO7)
unnamed: EPD_C1.1, J1.4
unnamed: EPD_C2.2, J1.5
unnamed: EPD_C6.1, J1.18
unnamed: EPD_C7.1, J1.19
unnamed: EPD_C8.1, J1.20
unnamed: EPD_C10.1, J1.22
unnamed: EPD_C12.1, J1.24
PREVGH: D5.1 (K), EPD_C9.1, J1.21
PREVGL: D4.2 (A), EPD_C11.1, J1.23
PROG: MCP73831.5 (PROG), R2_BAT.2
RESE: J1.3, Q3.2 (S), R3.2
RESE': R2.2, R3.1, SJ1.2
RESET: C5.1, IC1.1 (VOUT), RESET_BUTTON.3, RESET_BUTTON.4, R_RESET.1, U2.3 (EN)
RTC_RST: U2.16 (IO18), U3.4 (!RST)
RX: TP2.TP, U2.24 (RXD0/GPIO17)
SCK: D10.2, J1.13, J4.P5 (CLK), R6.1, TP8.TP, U1.6 (CLK), U2.6 (IO6)
SCL: J3.4, R2-PINH.1, SENSOR2.4 (SCK), U2.20 (IO22), U3.16 (SCL), U4.7 (SCL)
SDA: J3.3, R1_PINH.1, SENSOR2.3 (SDI), U2.19 (IO21), U3.15 (SDA), U4.8 (SDA)
SRC: C4.1, C4.2, D3.2 (A), D4.1 (K), D5.2 (A), L1.1, Q3.3 (D)
SS_SD: D8.2, J4.P2 (CD/DAT3), R10.1, U2.4 (IO4)
TX: TP1.TP, U2.25 (TXD0/GPIO16)
USB_D+: D1.1 (I/O1_1), U2.14 (IO13)
USB_D-: D1.3 (I/O2_1), U2.13 (IO12)
VBAT: C2_BAT.1, MCP73831.3 (VBAT), Q1.3 (D), TP3.TP, U4.2 (CELL), U4.3 (VDD)
VBUS: C1_BAT.1, C4_USB.1, C5_USB.1, CHG_LED.A, D1.5 (VBUS), D2.2 (ANODE), MCP73831.4 (VIN), PFMF.050.1.2, Q1.1 (G), R1_PWRUSB.2, TP14.TP
VRTC: C8.1, C10_SUPERCAP.2, R_CAPACITOR.1, U3.14 (VBAT)
VUSB: J2.A4, J2.A9, J2.B4, J2.B9, PFMF.050.1.1

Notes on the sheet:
USB C connector & ESD protection
LDO Voltage Regulator
SD0805S020S1R0
DMG2305UX-7
SD Card
Display Type Selector
E-Paper Drive Circuit
Li-Po Battery Charging Controller
ESP32 C6
PFMF.050.1
E-Paper Display Header
EPD Power
Environmental Sensor BME688
BME688
Voltage Supervisor + Reset & Boot / IO Button
Battery Charge Level
RTC Module DS3231SN
Test Pads
External NOR Flash 64MB
Qwiic / Stemma QT
SPI ESD Protection Lines
OpenBook Schematic
drawn by: Gabriel-Valentin Pitic
3/22/2025 5:58PM

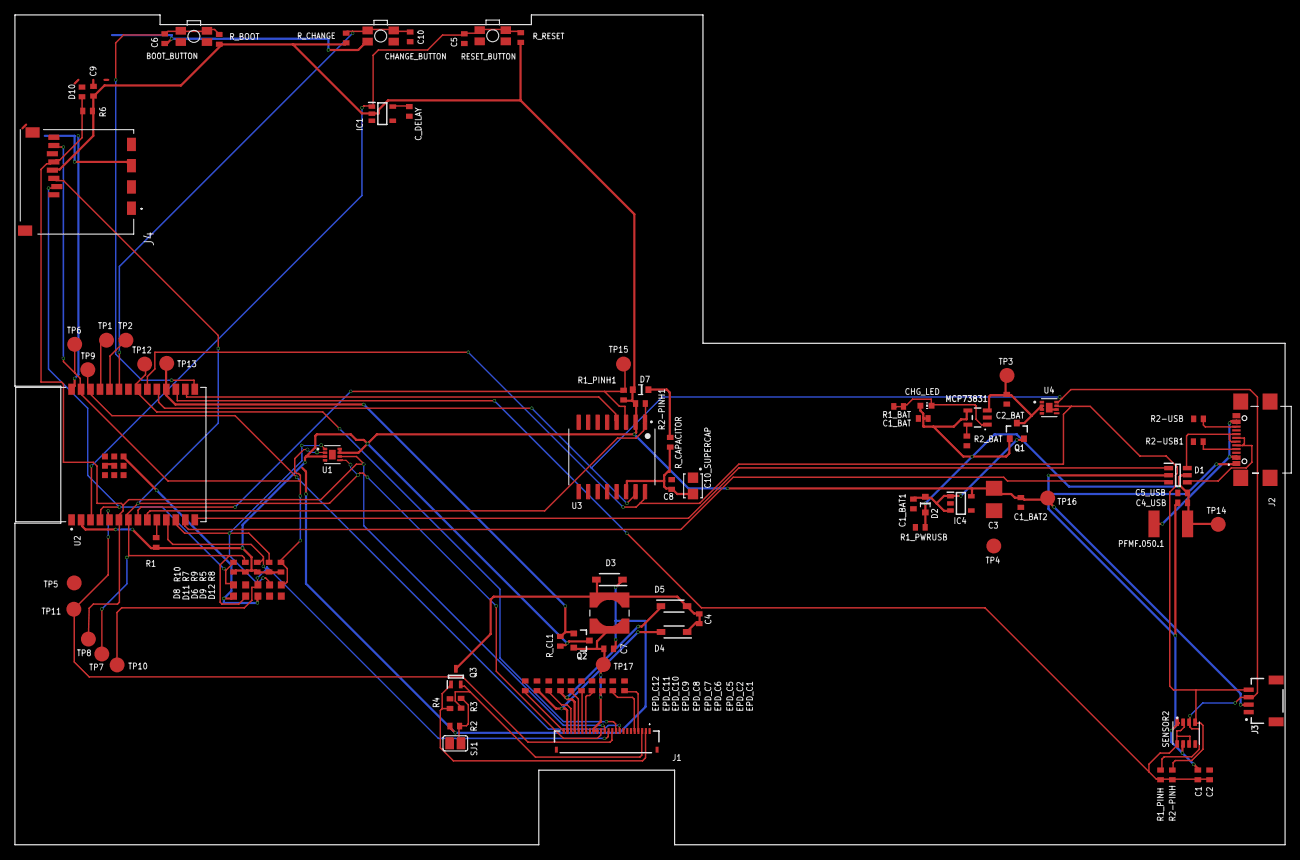
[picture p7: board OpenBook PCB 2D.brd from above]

Board: 2 copper layers, 170.2 x 111.2 mm, 103 parts (0 on the bottom side), 53 nets.

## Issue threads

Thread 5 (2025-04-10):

Hardware/Schematic

marinstef6, 2025-04-10:
De reparat urmatoarele probleme:

- Duplicarea numelui " PFMF.050.1"
- Numele suprapuse la cateva label-uri
- Conectarea firelor pentru EPD_C1

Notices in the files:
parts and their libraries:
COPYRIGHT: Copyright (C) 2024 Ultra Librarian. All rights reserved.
